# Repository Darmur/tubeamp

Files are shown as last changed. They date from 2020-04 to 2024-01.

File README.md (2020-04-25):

# tubeamp
**Class-A Vacuum Tube Hybrid Headphone Amplifier**

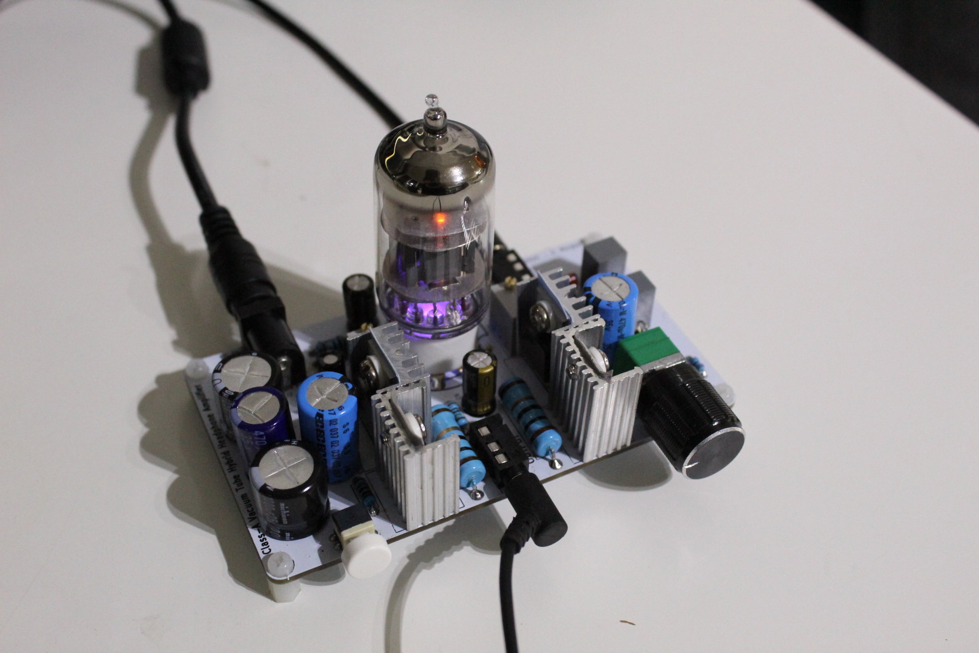
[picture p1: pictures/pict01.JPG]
TubeAmp naked


I've always been fascinated by vacuum tubes, some time ago I decided to start a small project with them, something simple and cheap, as a starting point. After some background study of audio amplifier design with vacuum tubes, I decided to design and build an headphone amplifier. I wanted it to be small, cheap but with excellent quality at the same time.

The outcome of this hobby project was a hybrid amplifier, with pre-amp stage made with dual-triode vacuum tube and power stage made by MOSFET. It can be powered with a relatively low voltage, something between 12.6V and 15V will be more than enough.

After manually soldering the components on the first prototype, I connected a 14V power supply and my Bose headphones. I was astonished and amazed by the quality of the sound, I could feel warm bass and crystal-clear trebles like I never did before with a pair of headphones.

Soldering components will not be too hard, for people with a bare minimum of soldering skills. In the BOM you will find links for buying components on Aliexpress, the total cost will be definitely small.

Please feel free to download gerber files and documentation, to order PCBs and to copy/improve it, if you like!

I hope you will enjoy this amplifier, as I enjoyed designing and building it.

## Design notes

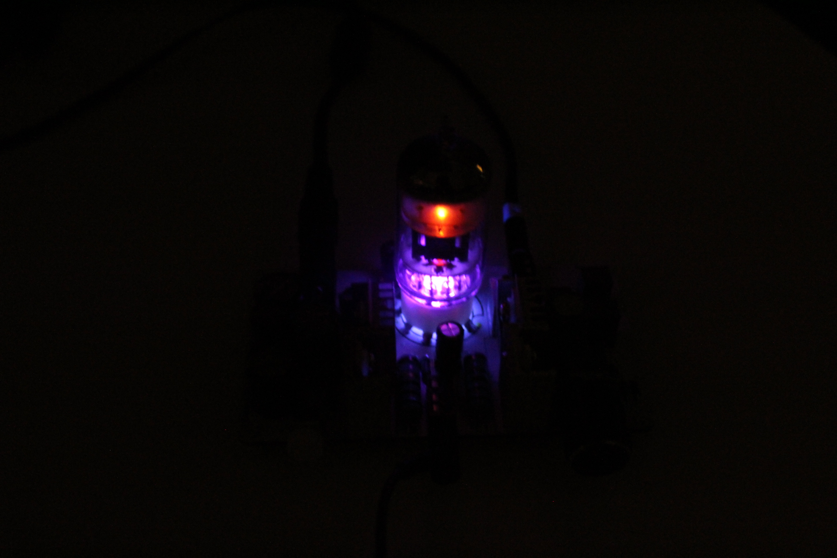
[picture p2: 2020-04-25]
pictures/pict04.JPG

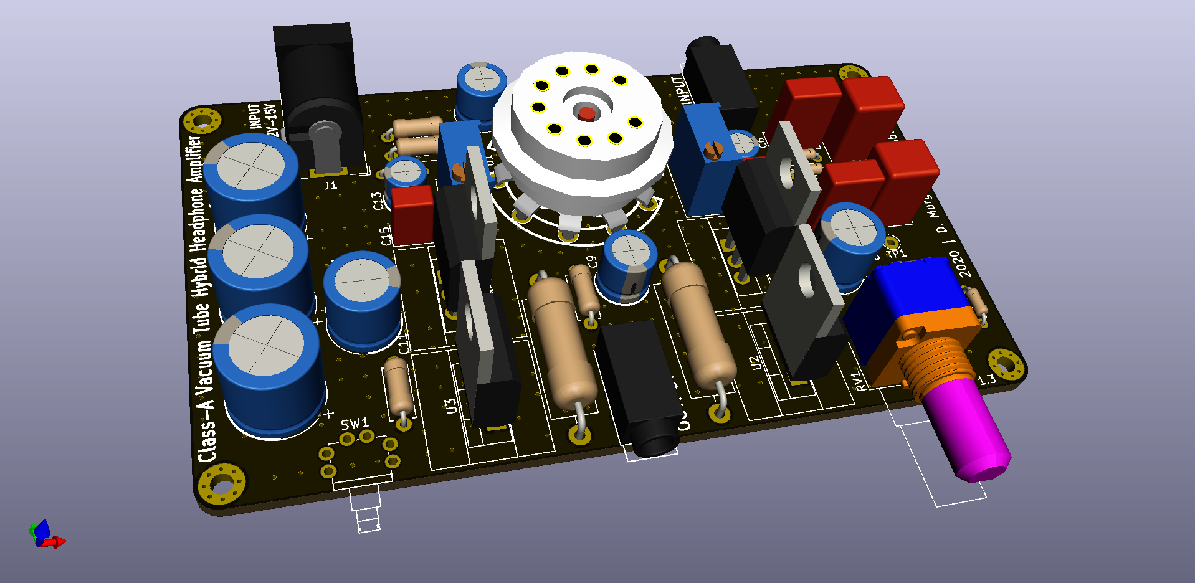
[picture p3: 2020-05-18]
TubeAmp.3D.png

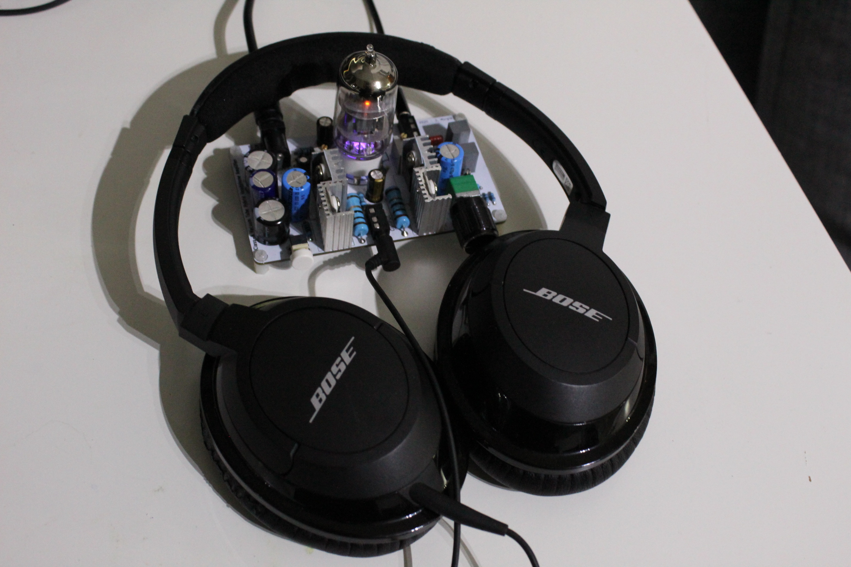
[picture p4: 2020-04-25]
pictures/pict02.JPG

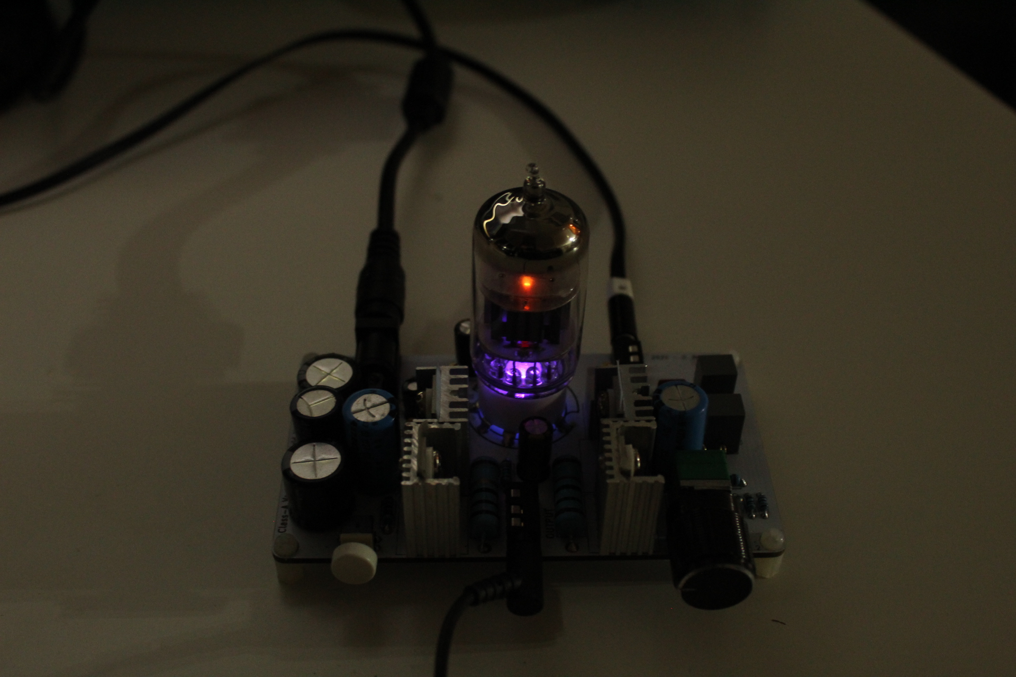
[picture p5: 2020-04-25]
pictures/pict03.JPG

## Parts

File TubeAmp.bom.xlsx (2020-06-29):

Reference | Quantity | Value | Link
C1 C2 C3 | 3 | CAP 1000UF/25V 10MM P7.5MM | https://www.aliexpress.com/item/32829549030.html
C10 C11 | 2 | CAP 470UF/16V 8MM P3.5MM | https://www.aliexpress.com/item/32864102646.html
C12 C13 | 2 | CAP 47UF/25V 5MM P2.5MM | https://www.aliexpress.com/item/32911787493.html
C14 C15 | 2 | CAP 100NF/50V 4.6X3MM P2.5MM | https://www.aliexpress.com/item/32865098104.html
C4 C5 | 2 | CAP 1.5UF/63V 7.2X6MM P5MM | https://www.aliexpress.com/item/4000461563828.html
C7 C6 | 2 | CAP 68PF/50V 7X3.5MM P5MM | https://www.aliexpress.com/item/32813120619.html
C9 C8 | 2 | CAP 100UF/25V 6.3MM P2.5MM | https://www.aliexpress.com/item/32803248529.html
D1 | 1 | LED BLUE 3MM | https://www.aliexpress.com/item/32890682652.html
J1 | 1 | DC BARREL JACK 5.5X2.1MM | https://www.aliexpress.com/item/33005175186.html
J2 J3 | 2 | AUDIO JACK 3.5 PJ-320A" | https://www.aliexpress.com/item/33029465106.html
Q1 Q2 | 2 | IRF510 POWER N-MOS TO-220 | https://www.aliexpress.com/item/32715627674.html
R1 R2 | 2 | RES 2K OHM 1/8W 3.6MM | https://www.aliexpress.com/item/33007959640.html
R11 R12 | 2 | RES 1M OHM 1/8W 3.6MM | https://www.aliexpress.com/item/33007959640.html
R13 R14 | 2 | RES 150 OHM 1/4W 6.3MM | https://www.aliexpress.com/item/32909364829.html
R15 R16 | 2 | RES 10 OHM 3W 15.5MM | https://www.aliexpress.com/item/4000773914003.html
R17 R18 | 2 | RES 1K OHM 1/4W 6.3MM | https://www.aliexpress.com/item/32909364829.html
R3 | 1 | RES 3.3K OHM 1/8W 3.6MM | https://www.aliexpress.com/item/33007959640.html
R4 R5 | 2 | RES 10 OHM 1/8W 3.6MM | https://www.aliexpress.com/item/33007959640.html
R6 | 1 | RES 5.6 OHM 1/4W 6.3MM | https://www.aliexpress.com/item/32909364829.html
R9 R10 | 2 | RES 6.8K OHM 1/8W 3.6MM | https://www.aliexpress.com/item/33007959640.html
R7 R8 | 2 | RES 100K OHM 1/8W 3.6MM | https://www.aliexpress.com/item/33007959640.html
RV1 | 1 | POT DUAL RK097G-B50K | https://www.aliexpress.com/item/1907441292.html
RV2 RV3 | 2 | POT 20K OHM 3296W | https://www.aliexpress.com/item/32845414733.html
SW1 | 1 | SWITCH ON/OFF PUSH BUTTON RIGHT ANGLE 5.8X5.8MM | https://www.aliexpress.com/item/4000316236780.html
U1 | 1 | 12AU7/ECC82 SOCKET GZC9-A-G | https://www.aliexpress.com/item/4000219880005.html
U2 U3 | 2 | LM317 VOLTAGE REGULATOR TO-220 | https://www.aliexpress.com/item/32549487669.html
TUBE | 1 | VACUUM TUBE 12AU7 | https://www.aliexpress.com/item/32816123723.html
HEATSINK | 4 | HEATSINK WITH SCREW FOR TO-220 | https://www.aliexpress.com/item/32802123591.html
KNOB | 1 | POTENTIOMETER KNOB | https://www.aliexpress.com/item/33005178438.html

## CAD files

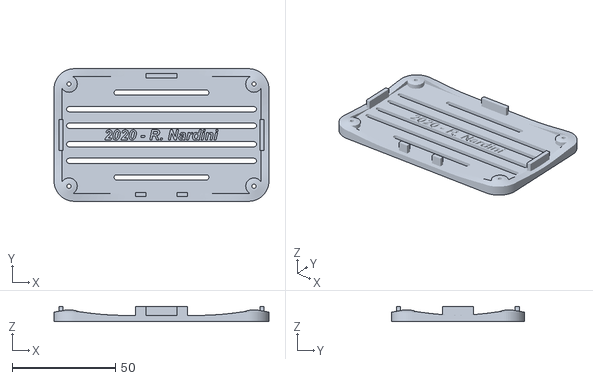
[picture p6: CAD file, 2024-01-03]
chassis/chassis-bottom.stl
103.9 x 64.1 x 7.30

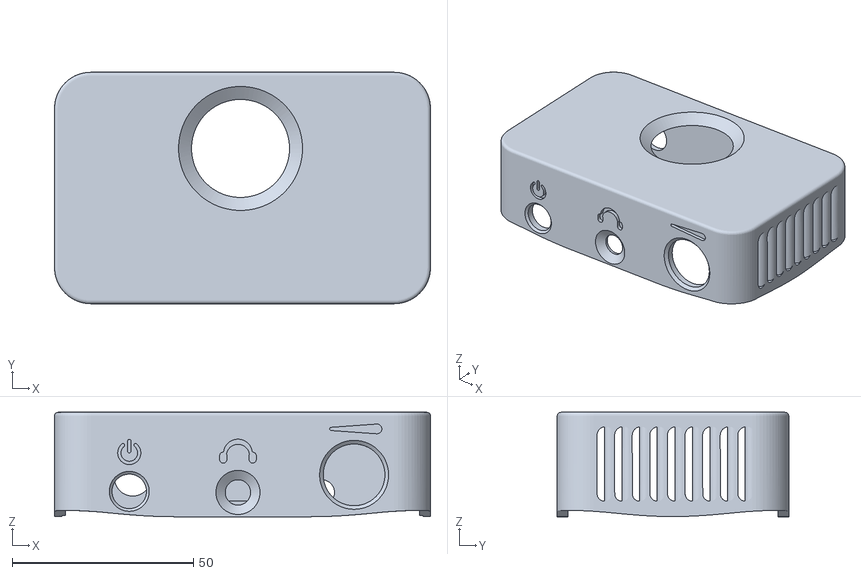
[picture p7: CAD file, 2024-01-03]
chassis/chassis-top.stl
103.6 x 63.8 x 28.8

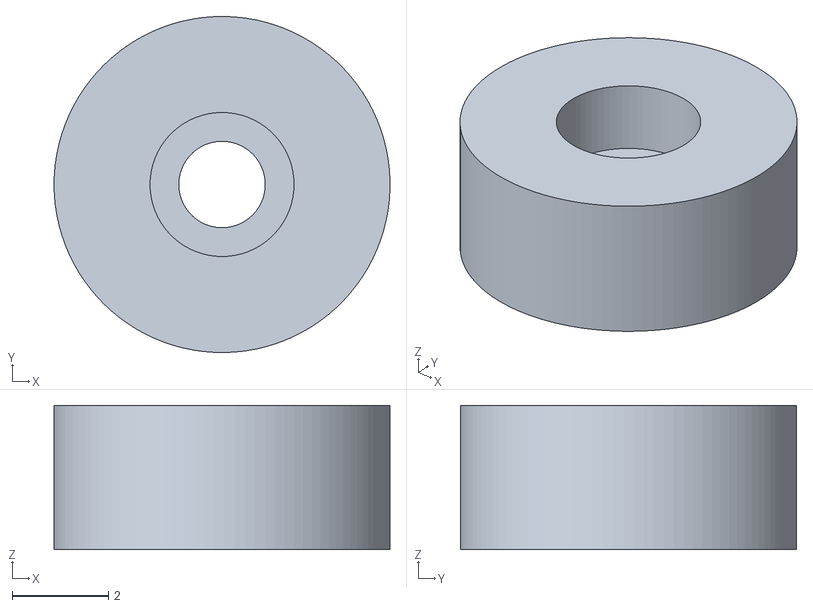
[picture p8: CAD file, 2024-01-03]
chassis/chassis-stand.stl
7.00 x 7.00 x 3.00

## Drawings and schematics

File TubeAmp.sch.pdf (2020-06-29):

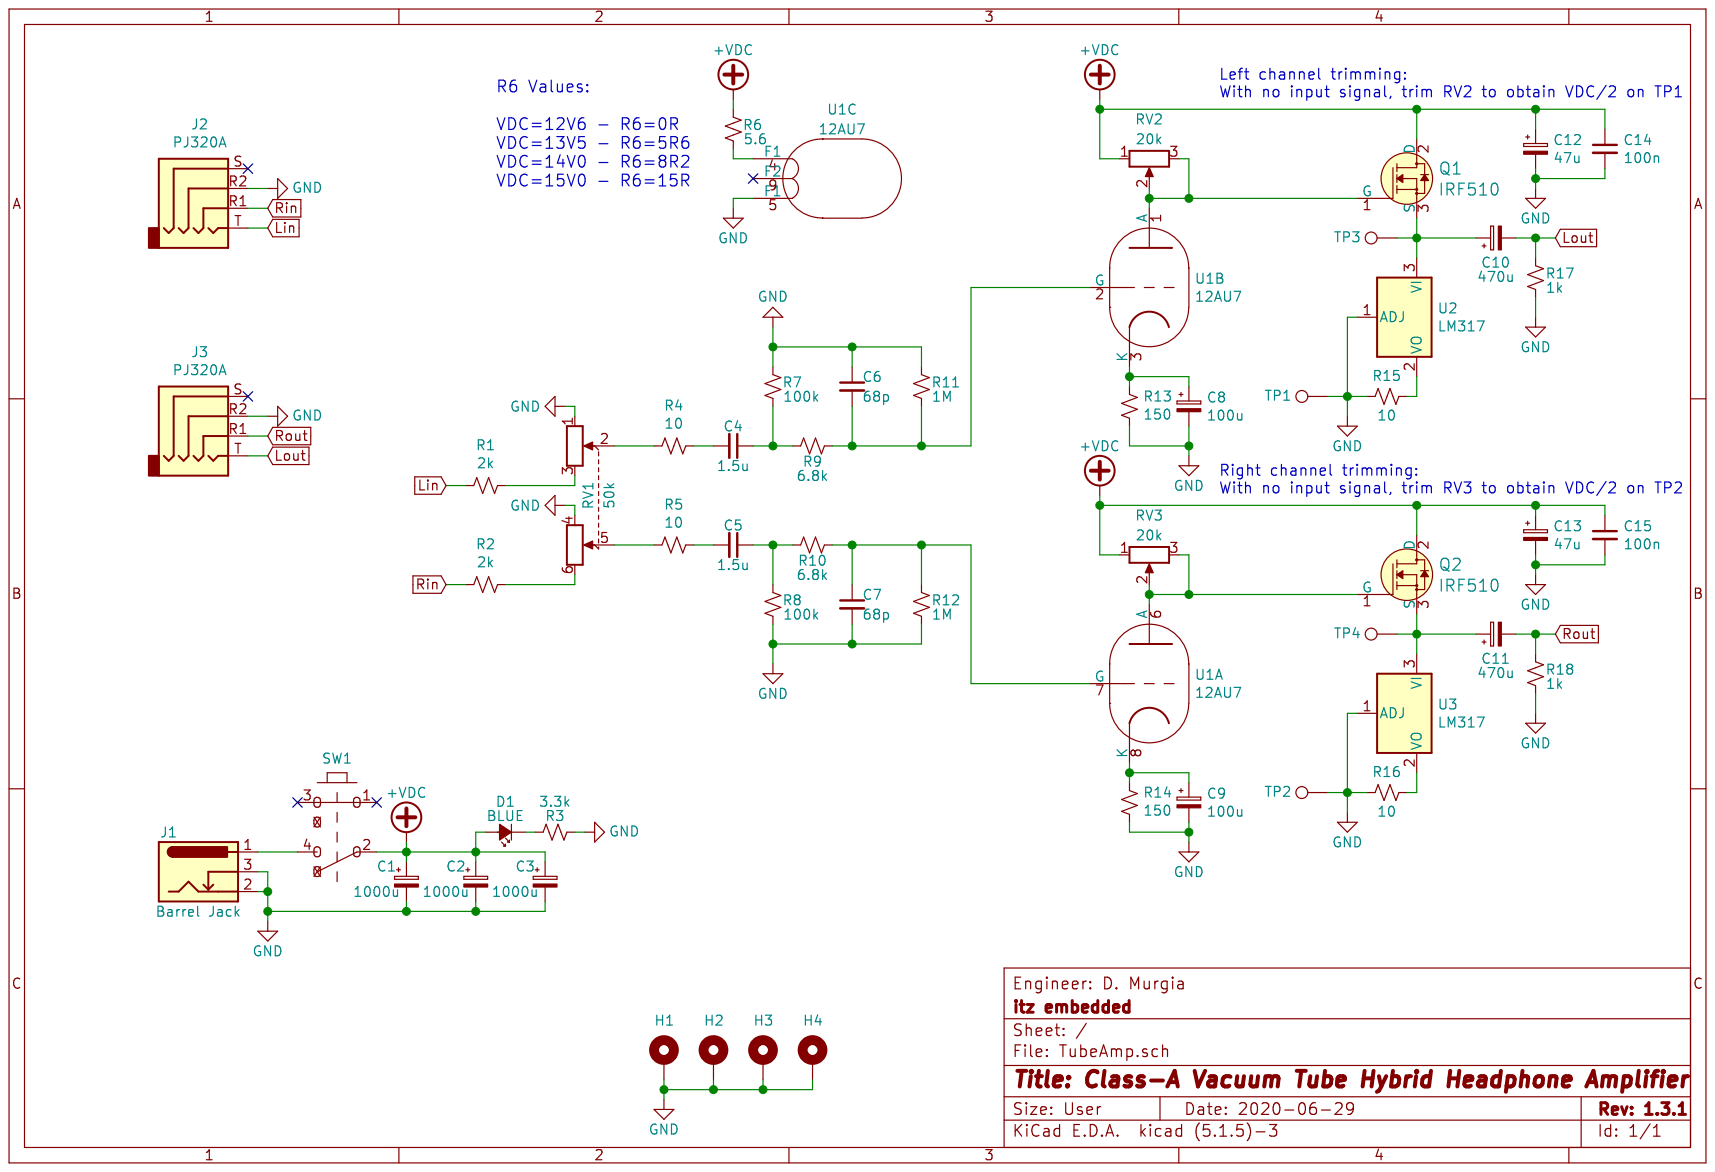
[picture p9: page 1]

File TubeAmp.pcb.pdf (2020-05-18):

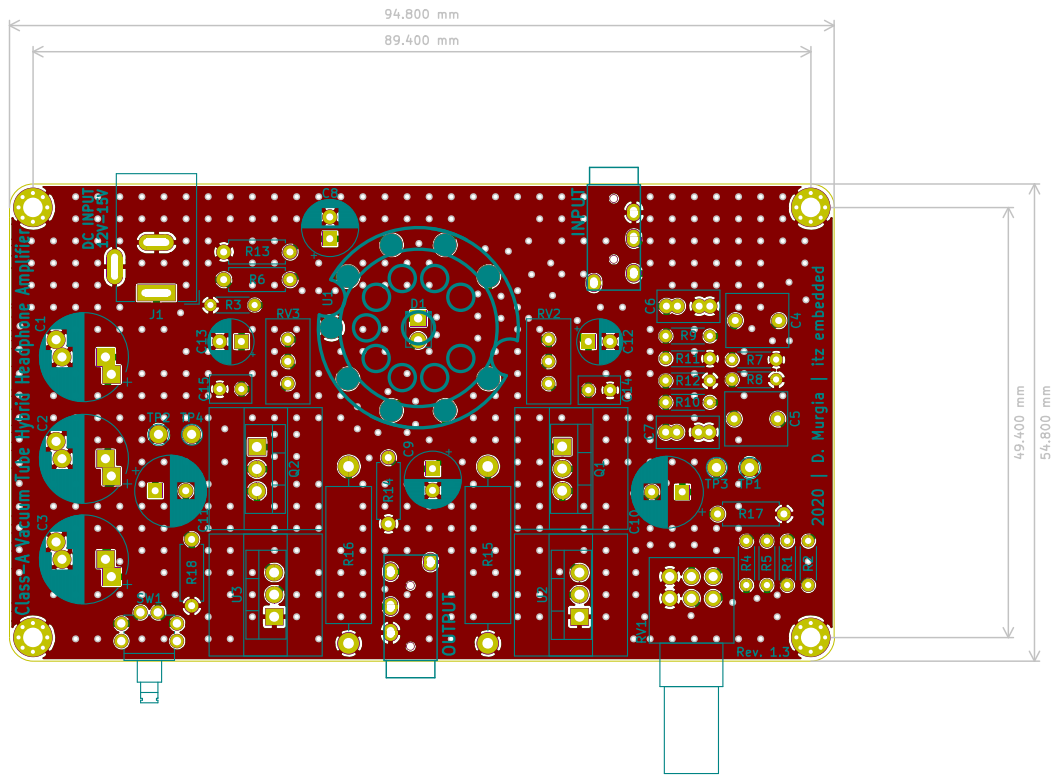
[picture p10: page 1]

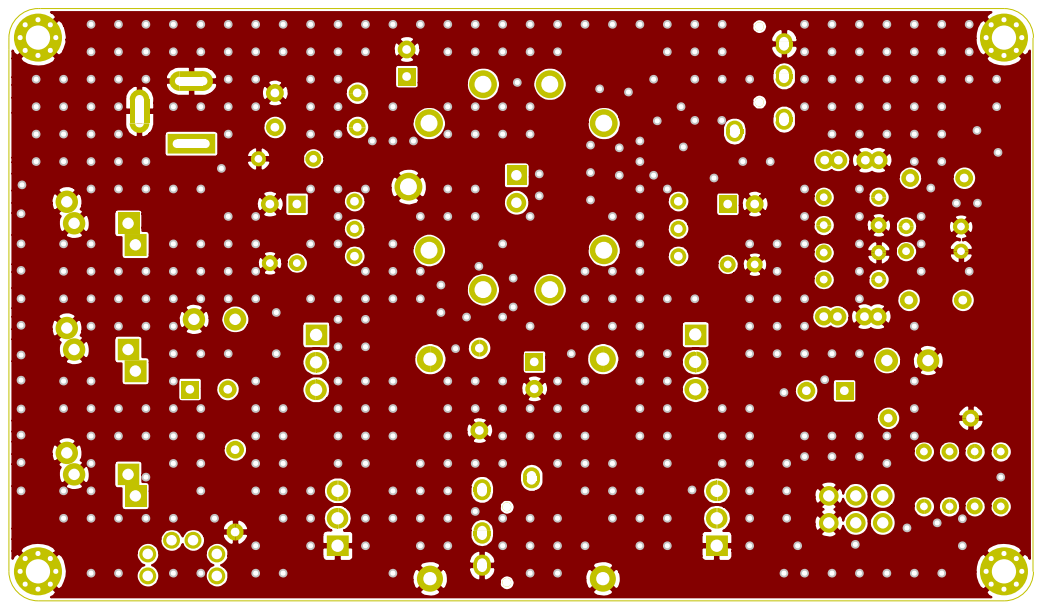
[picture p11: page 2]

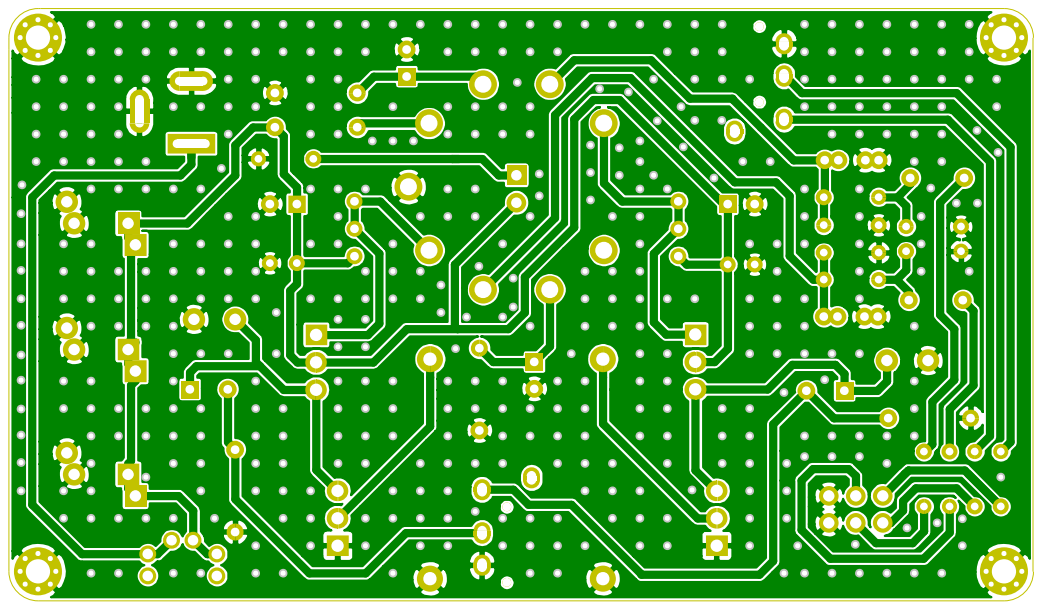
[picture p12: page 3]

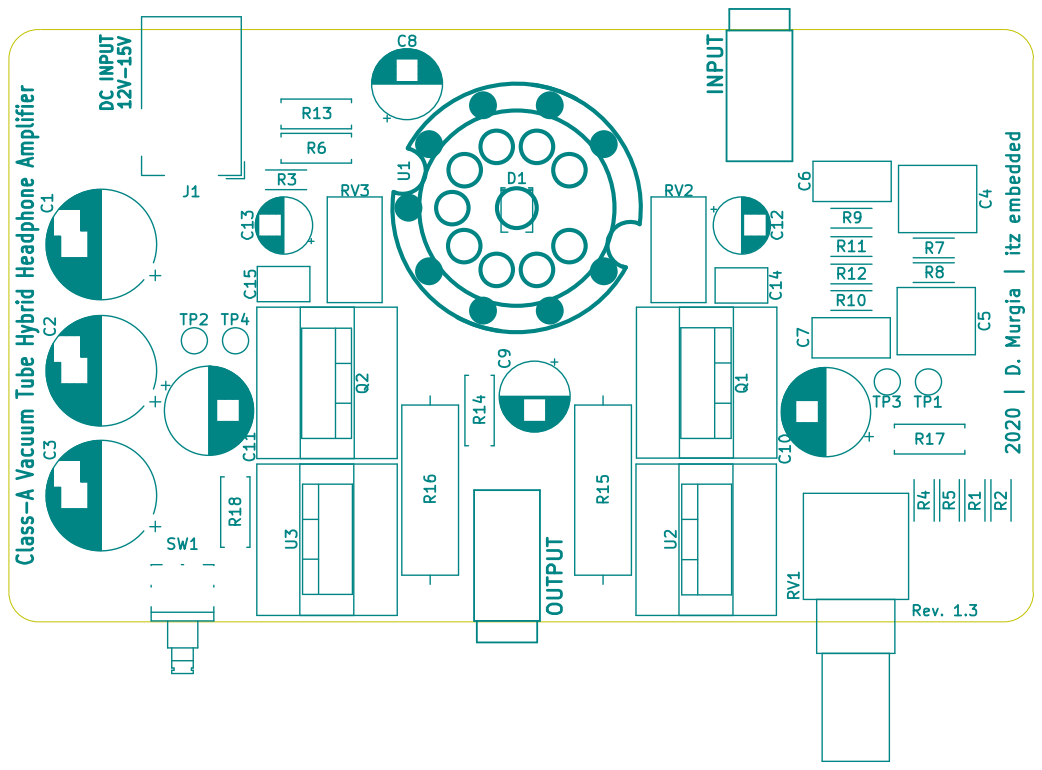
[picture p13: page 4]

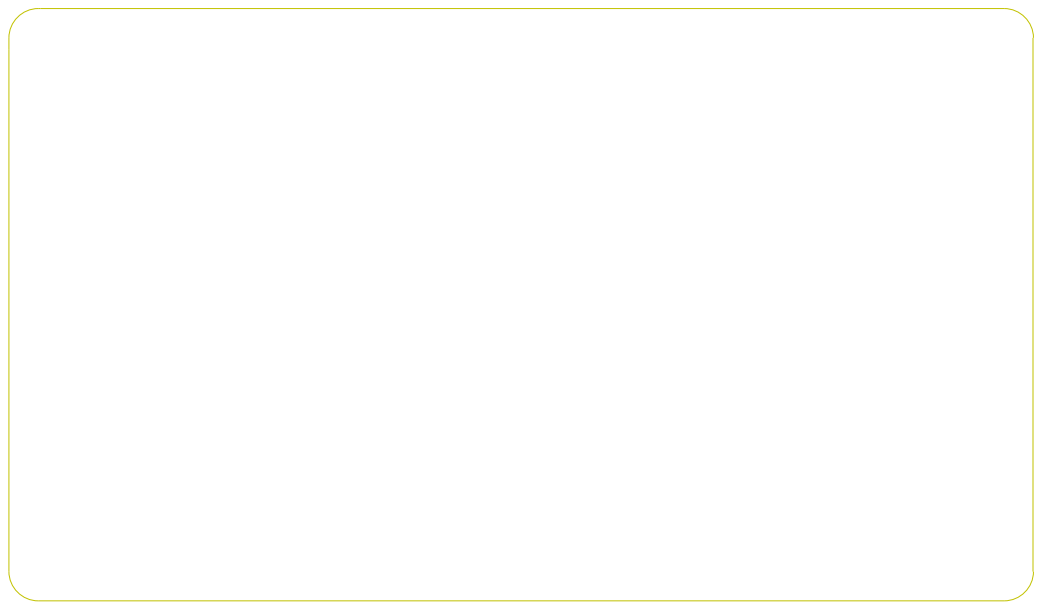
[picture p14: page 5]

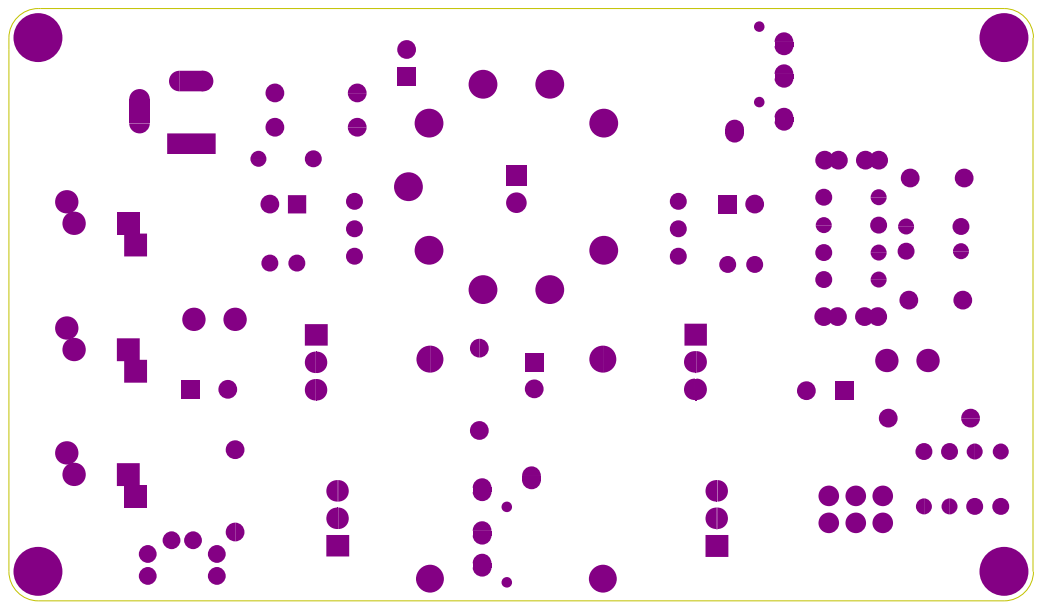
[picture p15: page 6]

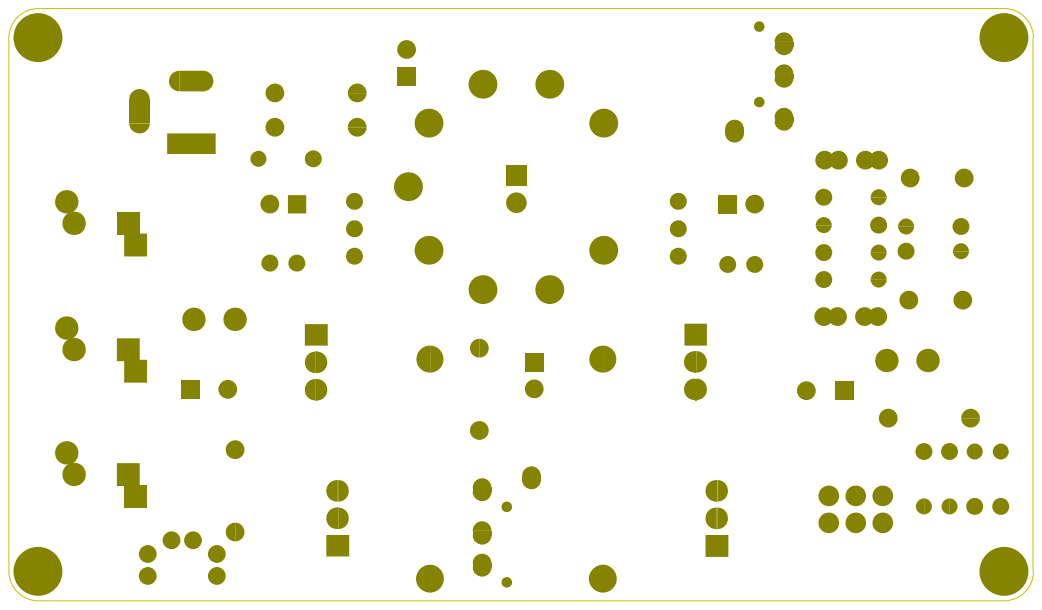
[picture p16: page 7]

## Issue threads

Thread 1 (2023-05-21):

"pick and place" file

jantyikt, 2023-05-21:
Maybe you could add a "pick and place" file to the project? I would like to order a pcb with assembly, for that I would need to provide to the pcb manufacturer (pcbways). I suppose I could somehow reproduce it from the gerber files...  it'd be great if I didn't have to, but had this attached to the project. (I'm a noob at this point in time, but I'm trying to learn from the example of this project.)

Darmur, 2023-05-22:
the pick&place files are required for SMD components, this design has only through-hole ones. even if I generate the pick&place file, it will be empty

jantyikt, 2023-05-22:
Hm, I see. Thank you very much for the information!

Closed 2023-05-22.

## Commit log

2020-03-13 added gerbers and documentation, project Rev1.2
    [TubeAmp.bom.xlsx]
2020-04-08 updated BOM, fixed some typos
    [TubeAmp.bom.xlsx]
2020-04-25 Updated value of C6/C7, frequency response is now flat between 20Hz and 20kHz
    [TubeAmp.bom.xlsx]
2020-05-18 Rev1.3, changed R9/R10/C6/C7 value, added 1MOhm resistors in parallel to C6/C7
    [TubeAmp.bom.xlsx]
2020-06-29 updated R9/R10 value to 6.8kOhm
    [TubeAmp.bom.xlsx]
2024-01-03 add chassis stl files
    [chassis-bottom.stl, chassis-stand.stl, chassis-top.stl]
